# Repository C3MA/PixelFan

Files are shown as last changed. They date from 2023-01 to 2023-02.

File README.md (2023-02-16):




# Projektbeschreibung
In diesem Projekt wurde ein Handelsüblicher Standventilator zum Rotationsdisplay umfunktioniert.

Details und eine Präsentation dazu gibt es hier:

[C3MA Vortrag](https://www.ccc-mannheim.de/wiki/Seminar_17._M%C3%A4rz_2023)

## Aufbau
Es gibt insgesamt 3 identische LED Leisten (PCB/LED_Leiste) mit jeweils 26 HD107S LEDs.

Die LED Leisten werden dann auf der Hauptplatine (PCB/PixelFan) bestückt.

Die Hauptplatine besteht aus 2 Controllern: 

* ein STM32G071KBTX (Software unter STM_PixelFan) für die schnelle zeitkritische Ansteuerung der LEDs und der Synchronisation zur Drehung
* ein ESP32 (Software unter ESP_PixelFan) um per W-LAN eine Verbindung zur Außenwelt herzustellen

Der Ventilator öffnet ein W-LAN (SSID: PixelFan) auf dem er eine Website (unter 192.168.4.1) anzeigt. Auf der Seite können Bilder, Smileys und Text auf den Ventilator gesendet werden.

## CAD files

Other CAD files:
PCB/LED_Leiste_Outline.FCStd
PCB/PCB_Outline.FCStd
PCB/LED_Leiste_Outline.dxf
PCB/PCB_Outline.dxf

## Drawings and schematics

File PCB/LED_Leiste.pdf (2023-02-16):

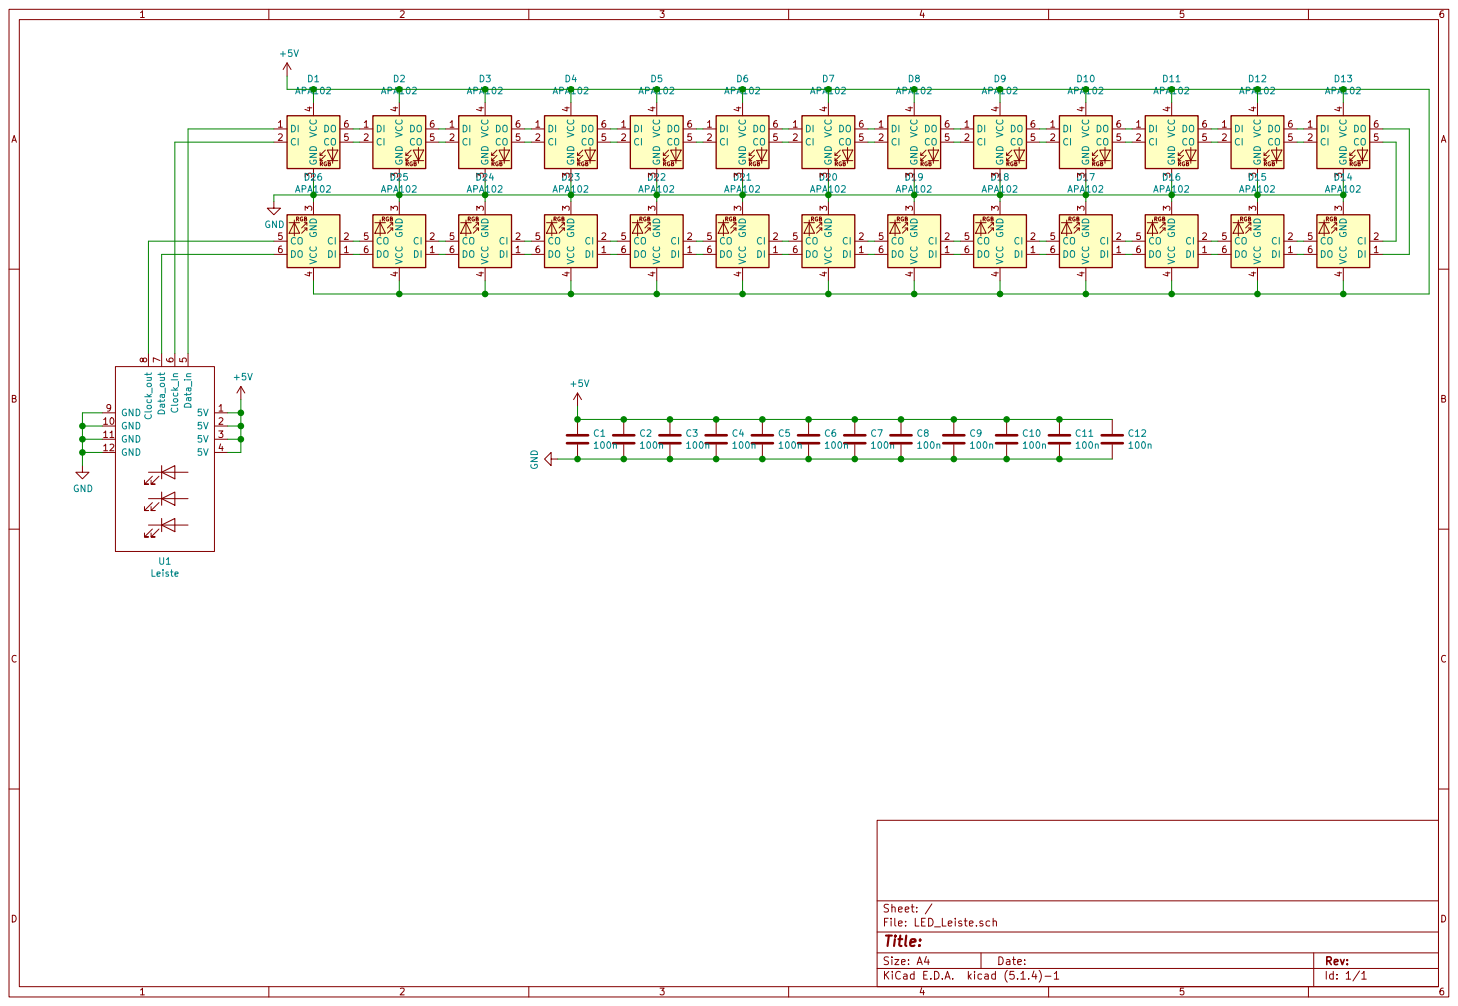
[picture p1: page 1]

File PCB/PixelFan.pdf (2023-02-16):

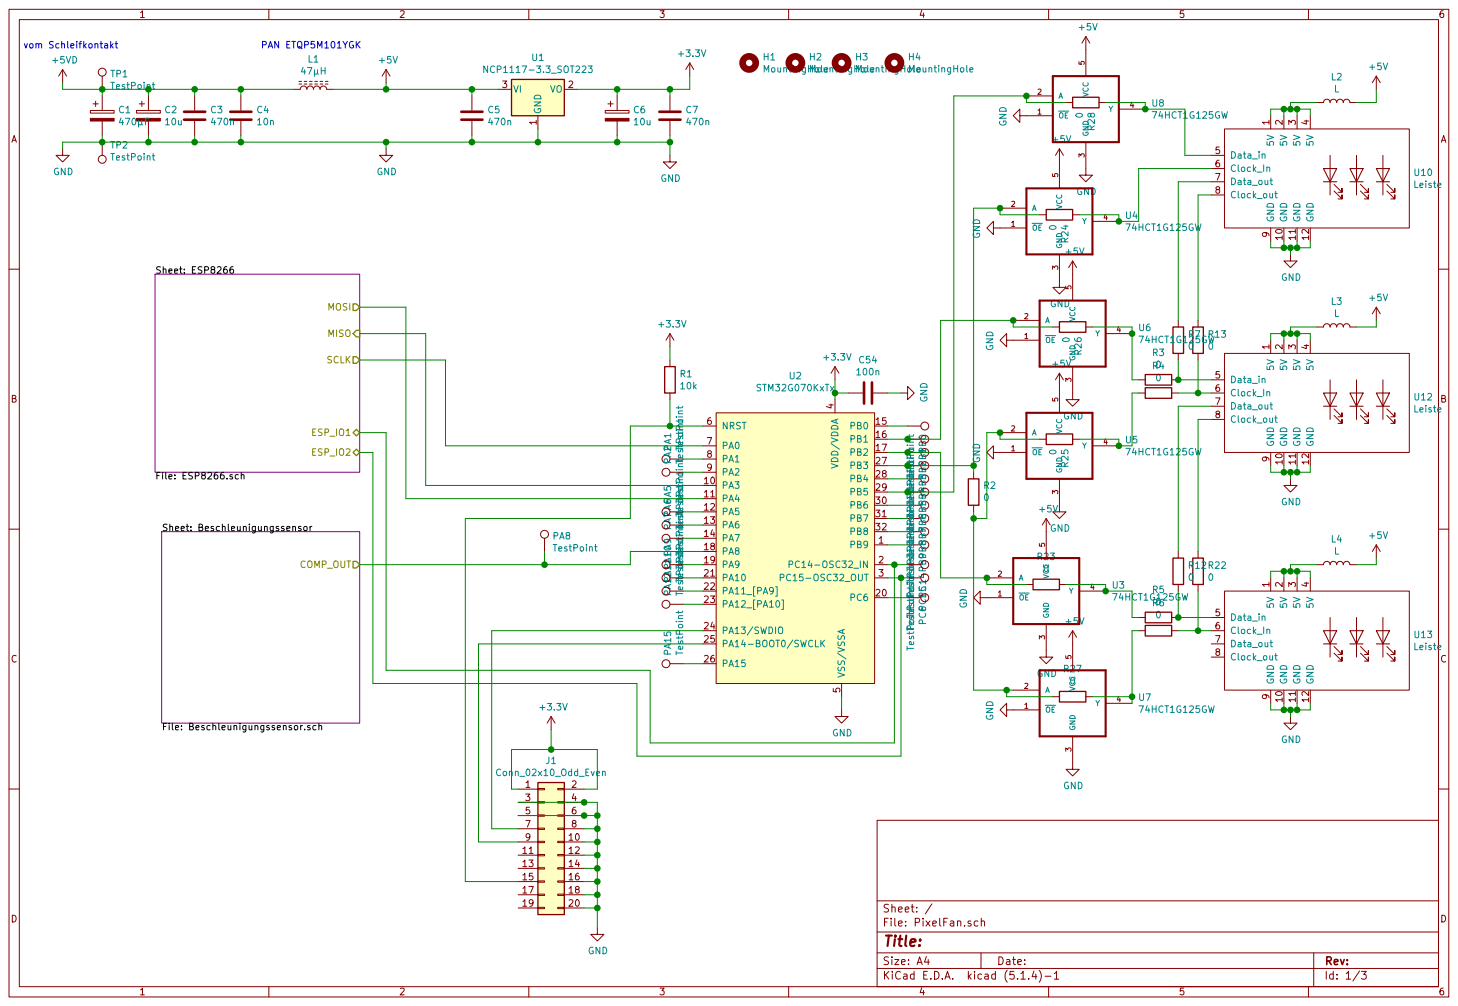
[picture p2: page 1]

Id: 1/3 Title: File: PixelFan.sch Sheet: / Sheet: Beschleunigungssensor

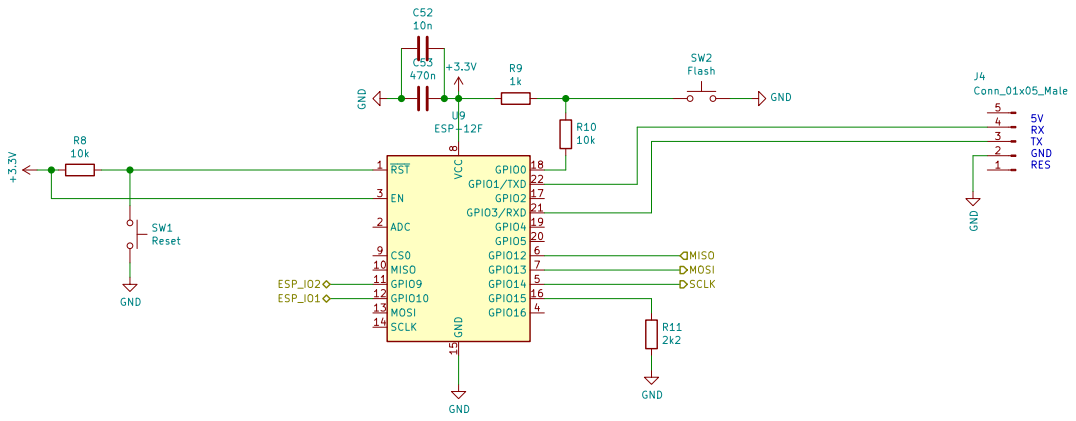
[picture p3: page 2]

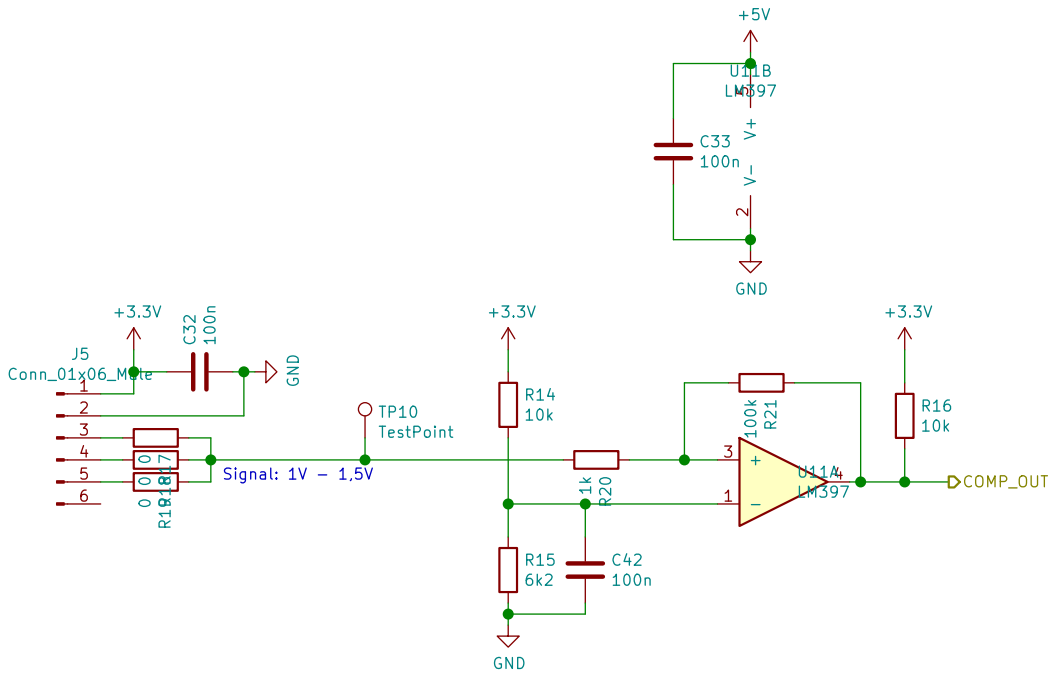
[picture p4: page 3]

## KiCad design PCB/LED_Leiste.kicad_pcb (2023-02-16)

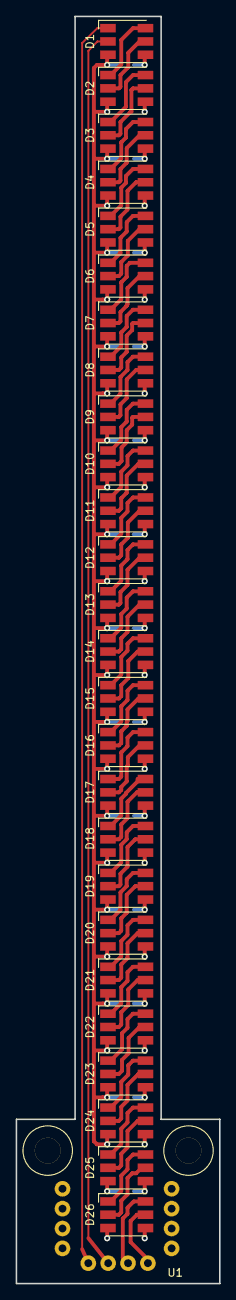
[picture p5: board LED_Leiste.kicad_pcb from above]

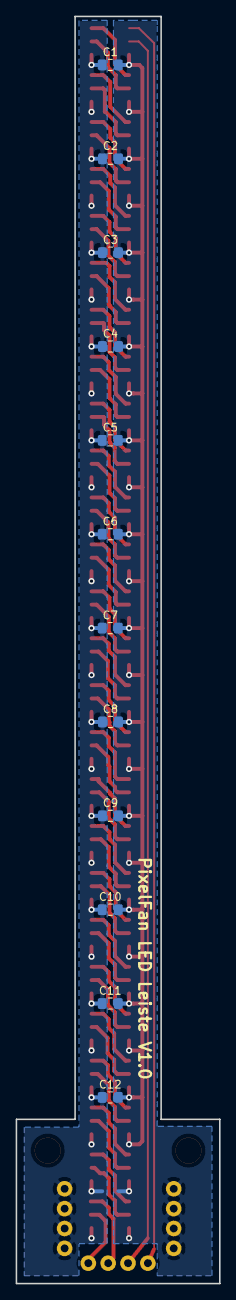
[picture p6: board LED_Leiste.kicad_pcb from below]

Board: 2 copper layers, 26.0 x 162.0 mm, 39 parts (12 on the bottom side), 56 nets.

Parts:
C1, C2, C3, C4, C5, C6, C7, C8, C9, C10, C11, C12: 100n; C_0805_2012Metric_Pad1.15x1.40mm_HandSolder
D1, D2, D3, D4, D5, D6, D7, D8, D9, D10, D11, D12, D13, D14, D15, D16, D17, D18, D19, D20, D21, D22, D23, D24, D25, D26: APA102; LED_RGB_5050-6
U1: Leiste; Leiste_NoOutline

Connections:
+5V: C1.1, C2.1, C3.1, C4.1, C5.1, C6.1, C7.1, C8.1, C9.1, C10.1, C11.1, C12.1, D1.4, D2.4, D3.4, D4.4, D5.4, D6.4, D7.4, D8.4, D9.4, D10.4, D11.4, D12.4, D13.4, D14.4, D15.4, D16.4, D17.4, D18.4, D19.4, D20.4, D21.4, D22.4, D23.4, D24.4, D25.4, D26.4, U1.1, U1.2, U1.3, U1.4
GND: C1.2, C2.2, C3.2, C4.2, C5.2, C6.2, C7.2, C8.2, C9.2, C10.2, C11.2, C12.2, D1.3, D2.3, D3.3, D4.3, D5.3, D6.3, D7.3, D8.3, D9.3, D10.3, D11.3, D12.3, D13.3, D14.3, D15.3, D16.3, D17.3, D18.3, D19.3, D20.3, D21.3, D22.3, D23.3, D24.3, D25.3, D26.3, U1.9, U1.10, U1.11, U1.12
unnamed: D1.1, U1.5
unnamed: D1.2, U1.6
unnamed: D1.5, D2.2
unnamed: D1.6, D2.1
unnamed: D2.5, D3.2
unnamed: D2.6, D3.1
unnamed: D3.5, D4.2
unnamed: D3.6, D4.1
unnamed: D4.5, D5.2
unnamed: D4.6, D5.1
unnamed: D5.5, D6.2
unnamed: D5.6, D6.1
unnamed: D6.5, D7.2
unnamed: D6.6, D7.1
unnamed: D7.5, D8.2
unnamed: D7.6, D8.1
unnamed: D8.5, D9.2
unnamed: D8.6, D9.1
unnamed: D9.6, D10.1
unnamed: D9.5, D10.2
unnamed: D10.5, D11.2
unnamed: D10.6, D11.1
unnamed: D11.5, D12.2
unnamed: D11.6, D12.1
unnamed: D12.5, D13.2
unnamed: D12.6, D13.1
unnamed: D13.5, D14.2
unnamed: D13.6, D14.1
unnamed: D14.5, D15.2
unnamed: D14.6, D15.1
unnamed: D15.5, D16.2
unnamed: D15.6, D16.1
unnamed: D16.5, D17.2
unnamed: D16.6, D17.1
unnamed: D17.5, D18.2
unnamed: D17.6, D18.1
unnamed: D18.5, D19.2
unnamed: D18.6, D19.1
unnamed: D19.5, D20.2
unnamed: D19.6, D20.1
unnamed: D20.5, D21.2
unnamed: D20.6, D21.1
unnamed: D21.5, D22.2
unnamed: D21.6, D22.1
unnamed: D22.5, D23.2
unnamed: D22.6, D23.1
unnamed: D23.5, D24.2
unnamed: D23.6, D24.1
unnamed: D24.5, D25.2
unnamed: D24.6, D25.1
unnamed: D25.5, D26.2
unnamed: D25.6, D26.1
unnamed: D26.5, U1.8
unnamed: D26.6, U1.7

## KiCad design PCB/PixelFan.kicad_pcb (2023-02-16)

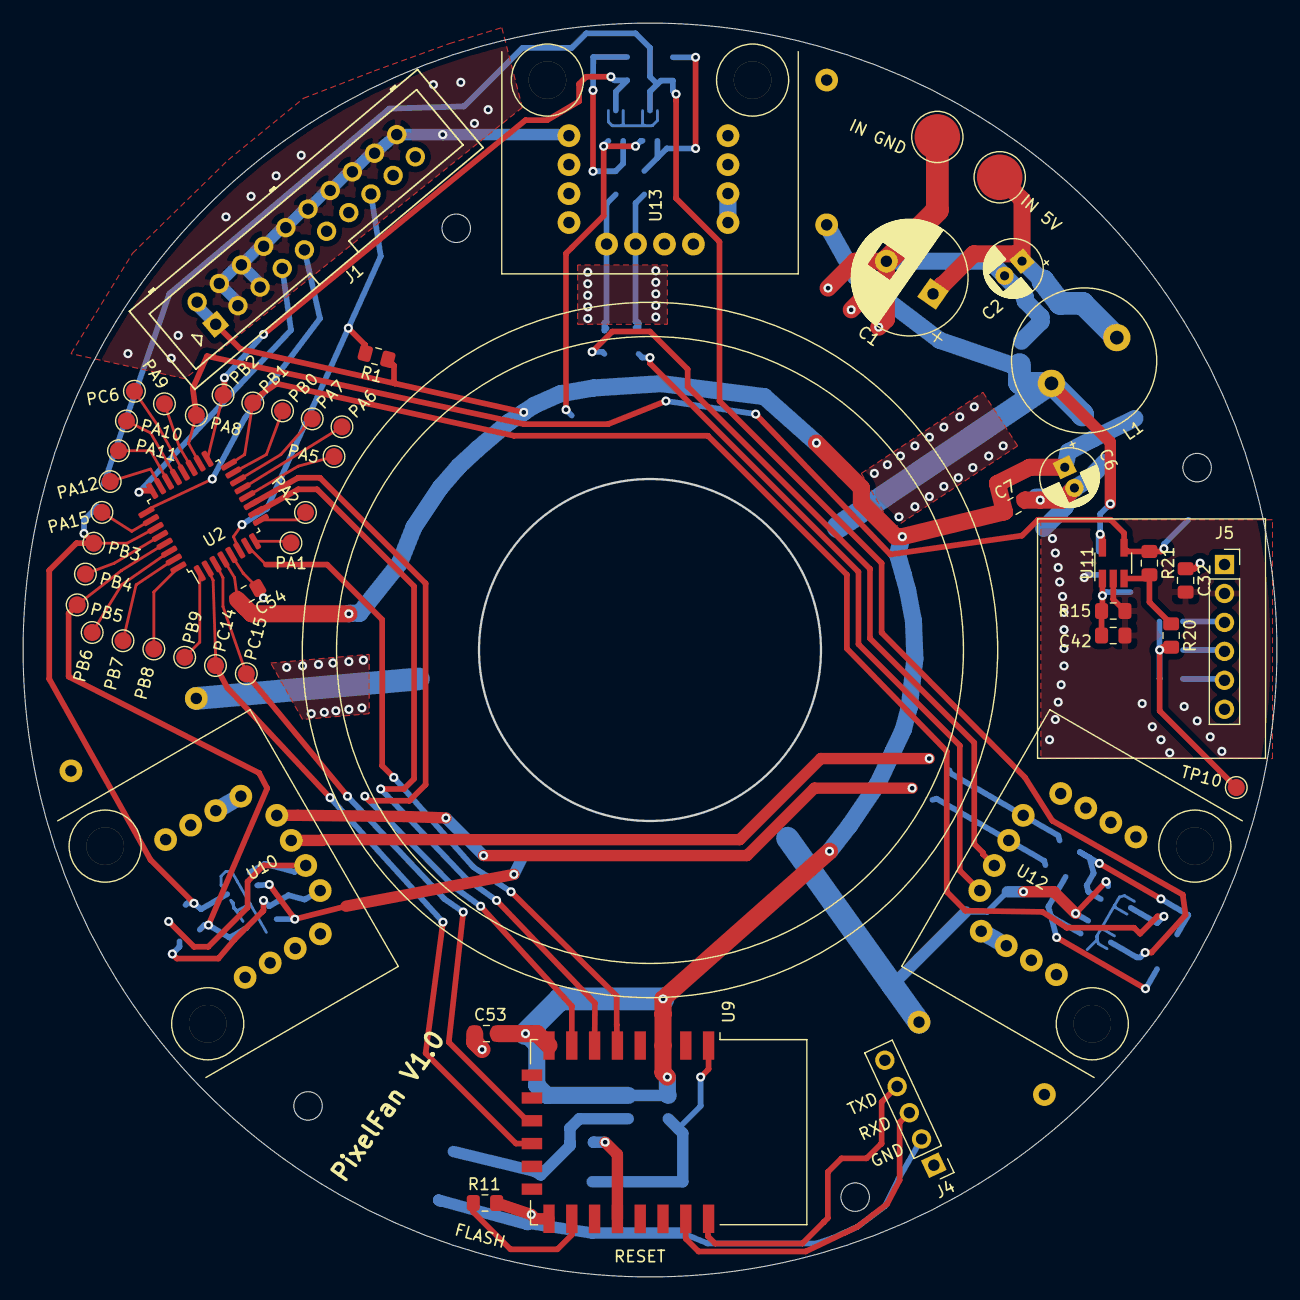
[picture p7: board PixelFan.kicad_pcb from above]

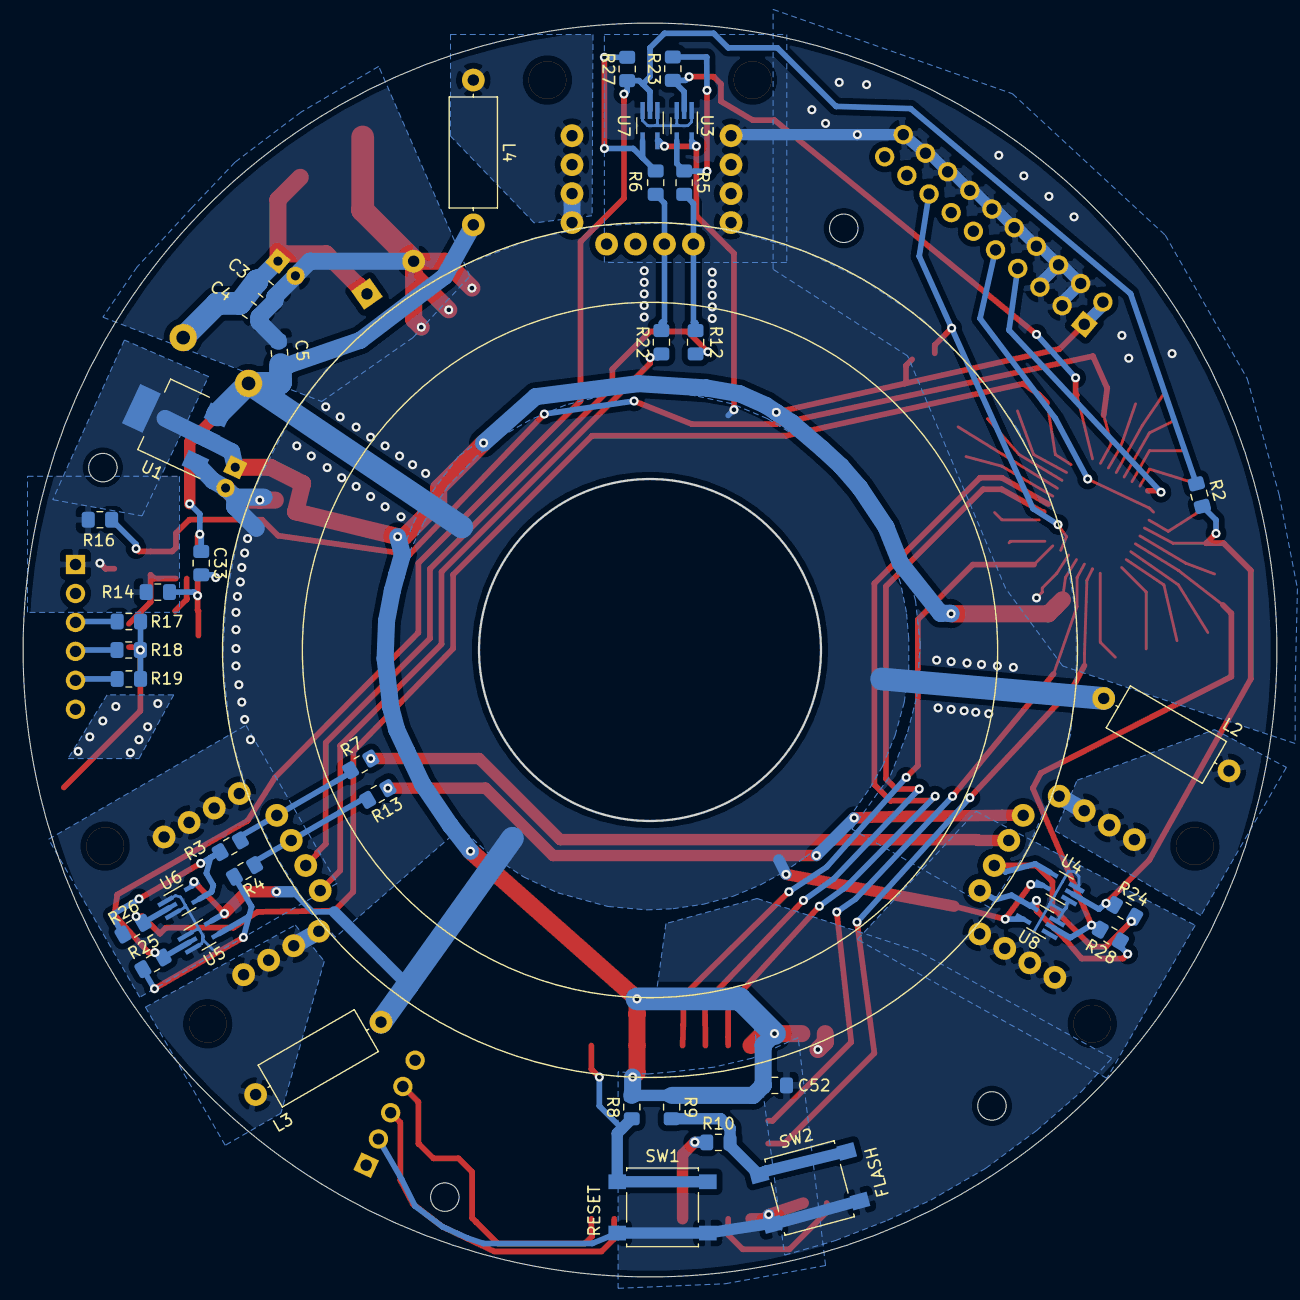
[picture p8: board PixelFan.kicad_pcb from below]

Board: 2 copper layers, 110.0 x 110.0 mm, 94 parts (40 on the bottom side), 64 nets.

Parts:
C1: 470µF; CP_Radial_D10.0mm_P5.00mm
C2, C6: 10u; CP_Radial_D5.0mm_P2.00mm
C3, C5, C7, C53: 470n; C_0805_2012Metric_Pad1.15x1.40mm_HandSolder
C4, C52: 10n; C_0805_2012Metric_Pad1.15x1.40mm_HandSolder
C32, C33, C42, C54: 100n; C_0805_2012Metric_Pad1.15x1.40mm_HandSolder
H1, H2, H3, H4: MountingHole; MountingHole_2.5mm
J1: Conn_02x10_Odd_Even; Multicomp_MC9A12-2034_2x10_P2.54mm_Vertical
J4: Conn_01x05_Male; PinHeader_1x05_P2.54mm_Vertical
J5: Conn_01x06_Male; PinSocket_1x06_P2.54mm_Vertical
L1: 47µH; L_Radial_D12.5mm_P7.00mm_Fastron_09HCP
L2, L3, L4: L; L_Axial_L9.5mm_D4.0mm_P12.70mm_Horizontal_Fastron_SMCC
PA1, PA2, PA5, PA6, PA7, PA8, PA9, PA10, PA11, PA12, PA15: TestPoint; TestPoint_Pad_D1.5mm
PB0, PB1, PB2, PB3, PB4, PB5, PB6, PB7, PB8, PB9: TestPoint; TestPoint_Pad_D1.5mm
PC6, PC14, PC15: TestPoint; TestPoint_Pad_D1.5mm
R1, R8, R10, R14, R16: 10k; R_0805_2012Metric_Pad1.15x1.40mm_HandSolder
R2, R3, R4, R5, R6, R7, R12, R13, R17, R18, R19, R22, R23, R24, R25, R26, R27, R28: 0; R_0805_2012Metric_Pad1.15x1.40mm_HandSolder
R9, R20: 1k; R_0805_2012Metric_Pad1.15x1.40mm_HandSolder
R11: 2k2; R_0805_2012Metric_Pad1.15x1.40mm_HandSolder
R15: 6k2; R_0805_2012Metric_Pad1.15x1.40mm_HandSolder
R21: 100k; R_0805_2012Metric_Pad1.15x1.40mm_HandSolder
SW1: Reset; SW_SPST_B3S-1000
SW2: Flash; SW_SPST_B3S-1000
TP1, TP2: TestPoint; TestPoint_Pad_D4.0mm
TP10: TestPoint; TestPoint_Pad_D1.5mm
U1: NCP1117-3.3_SOT223; SOT-223-3_TabPin2
U2: STM32G070KxTx; LQFP-32_7x7mm_P0.8mm
U3, U4, U5, U6, U7, U8: 74HCT1G125GW; SOT-353_SC-70-5_Handsoldering
U9: ESP-12F; ESP-12E
U10, U12, U13: Leiste; Leiste_WithOutline
U11: LM397; SOT-23-5_HandSoldering

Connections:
+3V3: C6.1, C7.1, C32.1, C52.1, C53.1, C54.2, J1.1, J1.2, J5.1, R1.1, R8.2, R9.1, R14.1, R16.1, U1.2, U2.4, U9.3, U9.8
+5V: C5.1, C33.1, L1.2, L2.2, L3.2, L4.2, U1.3, U3.5, U4.5, U5.5, U6.5, U7.5, U8.5, U11.5
+5VD: C1.1, C2.1, C3.1, C4.1, L1.1, TP1.1
/Beschleunigungssensor/COMP_OUT: PA8.1, R16.2, R21.1, U2.18, U11.4
/ESP8266/ESP_IO1: PC14.1, U2.2, U9.12
/ESP8266/ESP_IO2: PC15.1, U2.3, U9.11
/ESP8266/MISO: U2.10, U9.6
/ESP8266/MOSI: U2.11, U9.7
/ESP8266/SCLK: U2.7, U9.5
GND: C1.2, C2.2, C3.2, C4.2, C5.2, C6.2, C7.2, C32.2, C33.2, C42.2, C52.2, C53.2, C54.1, J1.3, J1.4, J1.5, J1.6, J1.8, J1.10, J1.12, J1.14, J1.16, J1.18, J1.20, J4.2, J5.2, R11.1, R15.2, SW1.2, SW2.2, TP2.1, U1.1, U2.5, U3.1, U3.3, U4.1, U4.3, U5.1, U5.3, U6.1, U6.3, U7.1, U7.3, U8.1, U8.3, U9.15, U10.9, U10.10, U10.11, U10.12, U11.2, U12.9, U12.10, U12.11, U12.12, U13.9, U13.10, U13.11, U13.12
unnamed: C42.1, R14.2, R15.1, U11.1
unnamed: J1.7, U2.24
unnamed: J1.9, U2.25
unnamed: J1.15, R1.2, U2.6
unnamed: J4.3, U9.21
unnamed: J4.4, U9.22
unnamed: J5.3, R17.2
unnamed: J5.4, R18.2
unnamed: J5.5, R19.2
unnamed: L2.1, U10.1, U10.2, U10.3, U10.4
unnamed: L3.1, U12.1, U12.2, U12.3, U12.4
unnamed: L4.1, U13.1, U13.2, U13.3, U13.4
unnamed: PA1.1, U2.8
unnamed: PA2.1, U2.9
unnamed: PA5.1, U2.12
unnamed: PA6.1, U2.13
unnamed: PA7.1, U2.14
unnamed: PA9.1, U2.19
unnamed: PA10.1, U2.21
unnamed: PA11.1, U2.22
unnamed: PA12.1, U2.23
unnamed: PA15.1, U2.26
unnamed: PB0.1, U2.15
unnamed: PB1.1, R26.2, U2.16, U6.2
unnamed: PB2.1, R23.1, U2.17, U3.2
unnamed: PB3.1, R2.2, R24.2, U2.27, U4.2
unnamed: PB4.1, U2.28
unnamed: PB5.1, R28.2, U2.29, U8.2
unnamed: PB6.1, U2.30
unnamed: PB7.1, U2.31
unnamed: PB8.1, U2.32
unnamed: PB9.1, U2.1
unnamed: PC6.1, U2.20
unnamed: R2.1, R25.2, R27.1, U5.2, U7.2
unnamed: R3.1, R7.2, U12.5
unnamed: R7.1, U10.7
unnamed: R8.1, SW1.1, U9.1
unnamed: R10.1, U9.18
unnamed: R9.2, R10.2, SW2.1
unnamed: R11.2, U9.16
unnamed: R12.1, U12.7
unnamed: R5.2, R12.2, U13.5
unnamed: R13.1, U10.8
unnamed: R4.1, R13.2, U12.6
unnamed: R17.1, R18.1, R19.1, R20.2, TP10.1
unnamed: R20.1, R21.2, U11.3
unnamed: R22.1, U12.8
unnamed: R6.2, R22.2, U13.6
unnamed: R5.1, R23.2, U3.4
unnamed: R24.1, U4.4, U10.6
unnamed: R4.2, R25.1, U5.4
unnamed: R3.2, R26.1, U6.4
unnamed: R6.1, R27.2, U7.4
unnamed: R28.1, U8.4, U10.5

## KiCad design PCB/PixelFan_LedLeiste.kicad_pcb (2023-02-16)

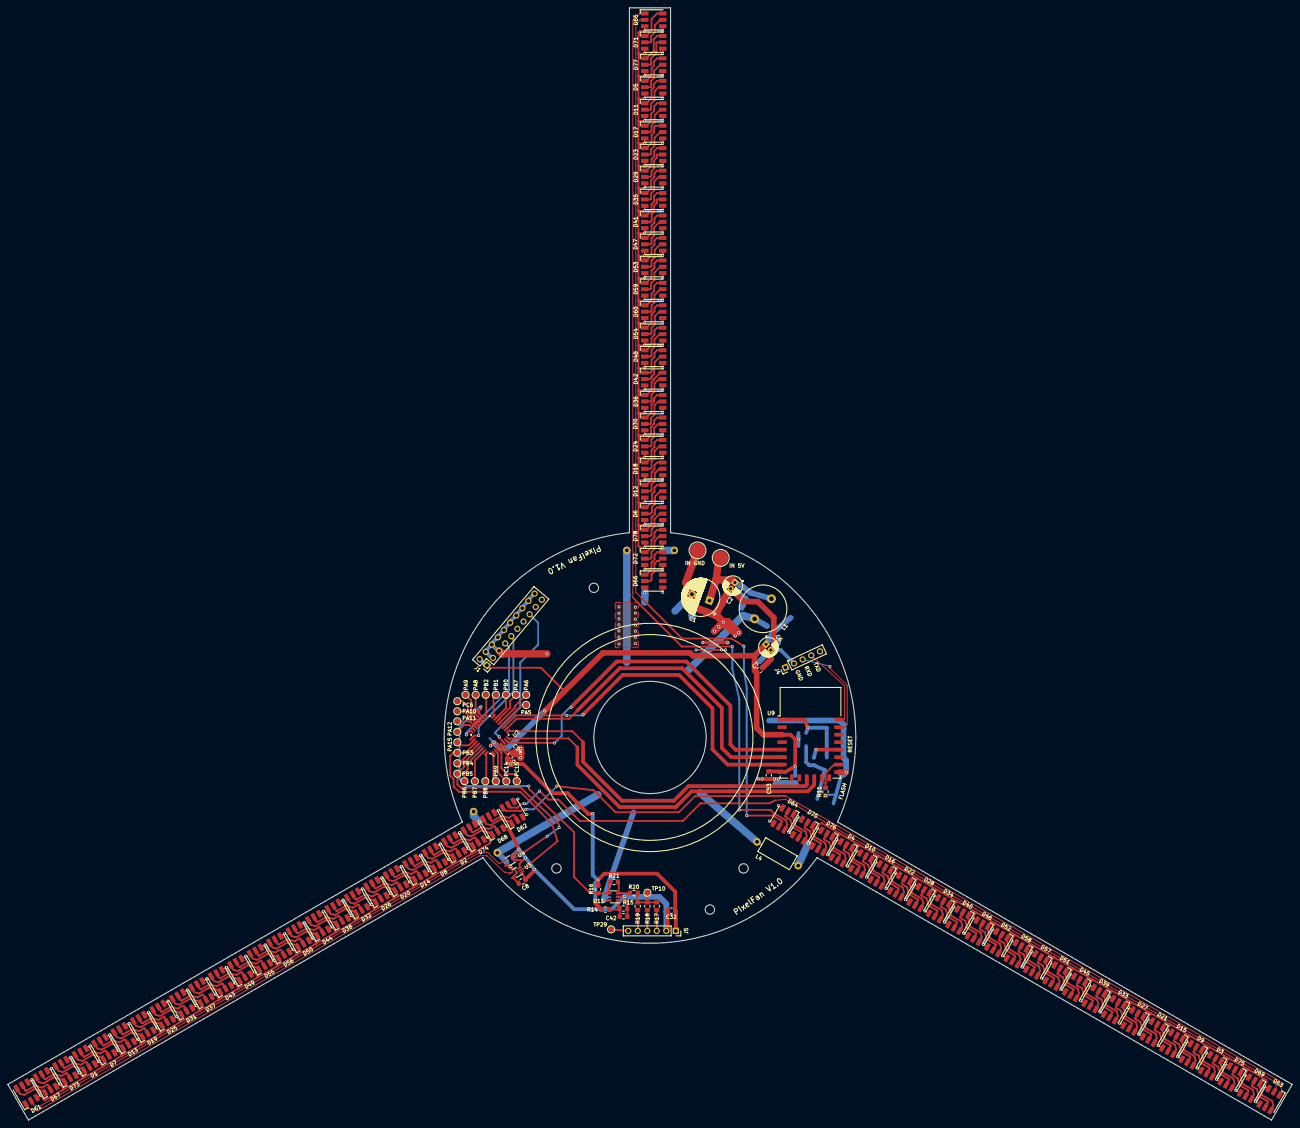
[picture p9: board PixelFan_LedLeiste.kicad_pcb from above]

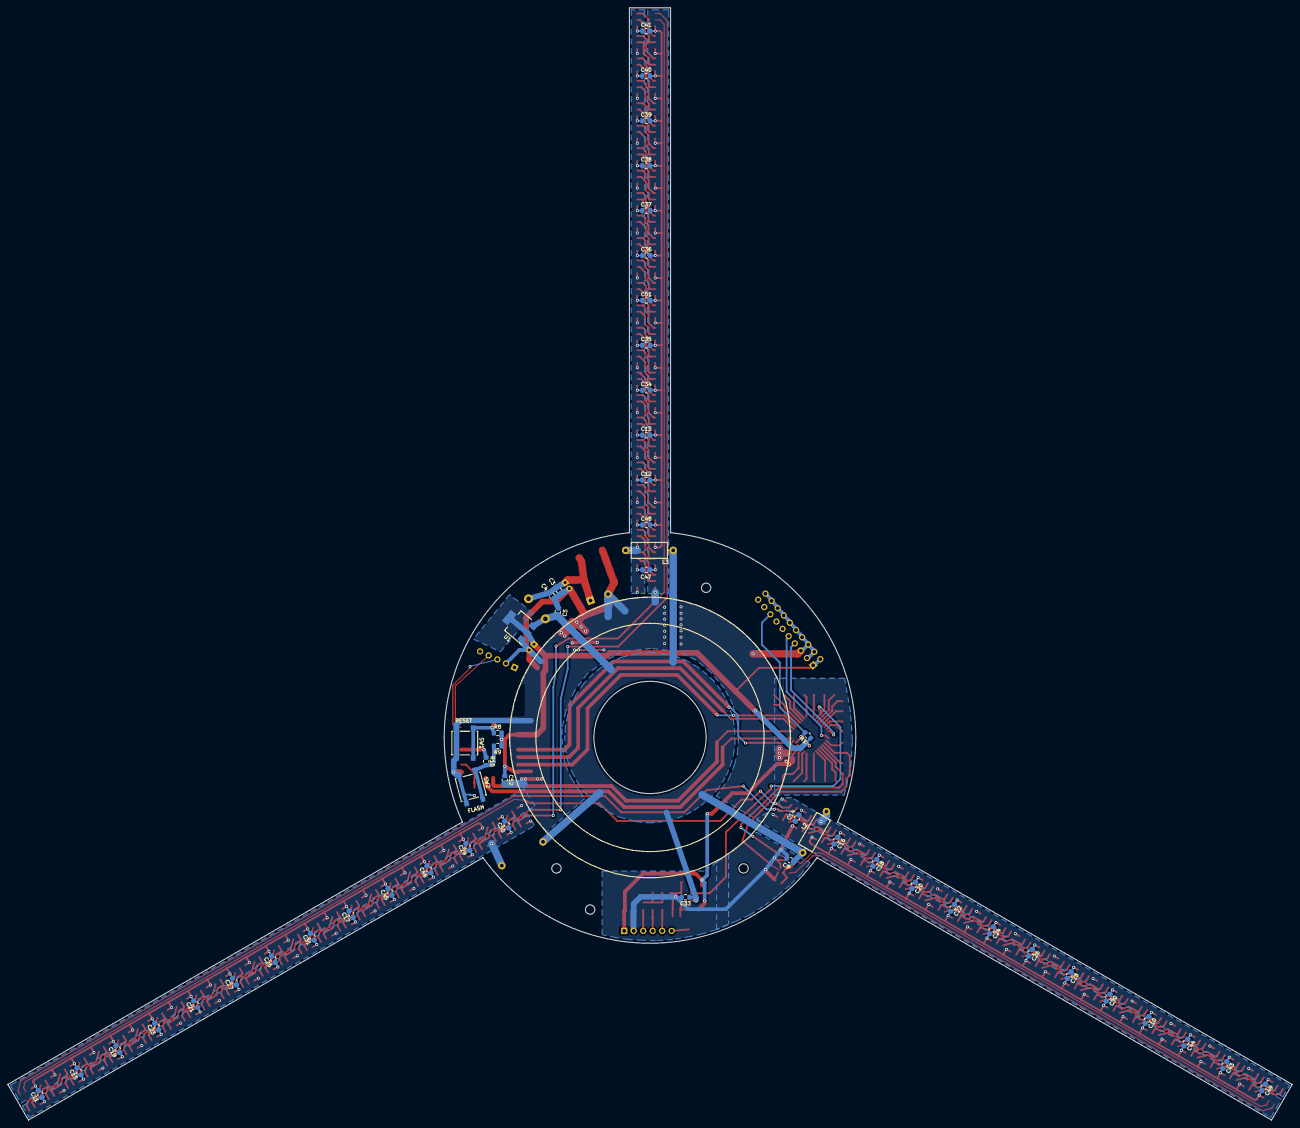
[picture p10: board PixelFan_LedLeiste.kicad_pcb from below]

Board: 2 copper layers, 343.2 x 297.3 mm, 190 parts (54 on the bottom side), 206 nets.

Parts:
C1: 470µF; CP_Radial_D10.0mm_P5.00mm
C2, C6: 10u; CP_Radial_D5.0mm_P2.00mm
C3, C5, C7, C53: 470n; C_0805_2012Metric_Pad1.15x1.40mm_HandSolder
C4, C52: 10n; C_0805_2012Metric_Pad1.15x1.40mm_HandSolder
C8, C9, C10, C11, C12, C13, C14, C15, C16, C17, C18, C19, C20, C21, C22, C23, C24, C25, C26, C27, C28, C29, C30, C31, C32, C33, C34, C35, C36, C37, C38, C39, C40, C41, C42, C43, C44, C45, C46, C47, C48, C49, C50, C51, C54: 100n; C_0805_2012Metric_Pad1.15x1.40mm_HandSolder
D1, D2, D3, D4, D5, D6, D7, D8, D9, D10, D11, D12, D13, D14, D15, D16, D17, D18, D19, D20, D21, D22, D23, D24, D25, D26, D27, D28, D29, D30, D31, D32, D33, D34, D35, D36, D37, D38, D39, D40, D41, D42, D43, D44, D45, D46, D47, D48, D49, D50, D51, D52, D53, D54, D55, D56, D57, D58, D59, D60, D61, D62, D63, D64, D65, D66, D67, D68, D69, D70, D71, D72, D73, D74, D75, D76, D77, D78: APA102; LED_RGB_5050-6
H1, H2, H3, H4: MountingHole; MountingHole_2.5mm
J1: Conn_02x10_Odd_Even; PinHeader_2x10_P2.54mm_Vertical
J4: Conn_01x05_Male; PinHeader_1x05_P2.54mm_Vertical
J5: Conn_01x06_Male; PinSocket_1x06_P2.54mm_Vertical
L1: 47µH; L_Radial_D12.5mm_P7.00mm_Fastron_09HCP
L2, L3, L4: 1u; L_Axial_L9.5mm_D4.0mm_P12.70mm_Horizontal_Fastron_SMCC
PA5, PA6, PA7, PA8, PA9, PA10, PA11, PA12, PA15: TestPoint; TestPoint_Pad_D1.5mm
PB0, PB1, PB2, PB3, PB4, PB5, PB6, PB7, PB8, PB9: TestPoint; TestPoint_Pad_D1.5mm
PC6, PC14, PC15: TestPoint; TestPoint_Pad_D1.5mm
R1, R8, R10, R14, R15, R16: 10k; R_0805_2012Metric_Pad1.15x1.40mm_HandSolder
R9, R20: 1k; R_0805_2012Metric_Pad1.15x1.40mm_HandSolder
R11: 2k2; R_0805_2012Metric_Pad1.15x1.40mm_HandSolder
R17, R18, R19: 0; R_0805_2012Metric_Pad1.15x1.40mm_HandSolder
R21: 100k; R_0805_2012Metric_Pad1.15x1.40mm_HandSolder
SW1: Reset; SW_SPST_B3S-1000
SW2: Flash; SW_SPST_B3S-1000
TP1, TP2: TestPoint; TestPoint_Pad_D4.0mm
TP10, TP29: TestPoint; TestPoint_Pad_D1.5mm
U1: NCP1117-3.3_SOT223; SOT-223-3_TabPin2
U2: STM32G070KxTx; LQFP-32_7x7mm_P0.8mm
U3, U4: 74HCT1G125GW; SOT-353_SC-70-5_Handsoldering
U9: ESP-12F; ESP-12E
U11: LM397; SOT-23-5_HandSoldering

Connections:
+3V3: C6.1, C7.1, C32.1, C52.1, C53.1, C54.2, J1.1, J1.2, J5.1, R1.1, R8.2, R9.1, R14.1, R16.1, U1.2, U2.4, U9.3, U9.8
+5V: C5.1, C8.1, C9.2, C33.1, L1.2, L2.1, L3.1, L4.1, U1.3, U3.5, U4.5, U11.5
+5VD: C1.1, C2.1, C3.1, C4.1, L1.1, TP1.1
/Beschleunigungssensor/COMP_OUT: PA8.1, R16.2, R21.1, U2.18, U11.4
/ESP8266/ESP_IO1: U2.8, U9.12
/ESP8266/ESP_IO2: U2.9, U9.11
/ESP8266/MISO: U2.10, U9.6
/ESP8266/MOSI: U2.11, U9.7
/ESP8266/SCLK: U2.7, U9.5
/LEDs/CLK: PB3.1, U2.27, U3.2
/LEDs/DATA: PB5.1, U2.29, U4.2
/LEDs/VCC_LINE1: C10.1, C14.1, C16.1, C18.1, C20.1, C22.1, C24.1, C26.1, C28.1, C30.1, C43.1, C44.1, C49.1, D1.4, D2.4, D7.4, D8.4, D13.4, D14.4, D19.4, D20.4, D25.4, D26.4, D31.4, D32.4, D37.4, D38.4, D43.4, D44.4, D49.4, D50.4, D55.4, D56.4, D61.4, D62.4, D67.4, D68.4, D73.4, D74.4, L2.2
/LEDs/VCC_LINE2: C11.1, C15.1, C17.1, C19.1, C21.1, C23.1, C25.1, C27.1, C29.1, C31.1, C45.1, C46.1, C50.1, D3.4, D4.4, D9.4, D10.4, D15.4, D16.4, D21.4, D22.4, D27.4, D28.4, D33.4, D34.4, D39.4, D40.4, D45.4, D46.4, D51.4, D52.4, D57.4, D58.4, D63.4, D64.4, D69.4, D70.4, D75.4, D76.4, L4.2
/LEDs/VCC_LINE3: C12.1, C13.1, C34.1, C35.1, C36.1, C37.1, C38.1, C39.1, C40.1, C41.1, C47.1, C48.1, C51.1, D5.4, D6.4, D11.4, D12.4, D17.4, D18.4, D23.4, D24.4, D29.4, D30.4, D35.4, D36.4, D41.4, D42.4, D47.4, D48.4, D53.4, D54.4, D59.4, D60.4, D65.4, D66.4, D71.4, D72.4, D77.4, D78.4, L3.2
GND: C1.2, C2.2, C3.2, C4.2, C5.2, C6.2, C7.2, C8.2, C9.1, C10.2, C11.2, C12.2, C13.2, C14.2, C15.2, C16.2, C17.2, C18.2, C19.2, C20.2, C21.2, C22.2, C23.2, C24.2, C25.2, C26.2, C27.2, C28.2, C29.2, C30.2, C31.2, C32.2, C33.2, C34.2, C35.2, C36.2, C37.2, C38.2, C39.2, C40.2, C41.2, C42.2, C43.2, C44.2, C45.2, C46.2, C47.2, C48.2, C49.2, C50.2, C51.2, C52.2, C53.2, C54.1, D1.3, D2.3, D3.3, D4.3, D5.3, D6.3, D7.3, D8.3, D9.3, D10.3, D11.3, D12.3, D13.3, D14.3, D15.3, D16.3, D17.3, D18.3, D19.3, D20.3, D21.3, D22.3, D23.3, D24.3, D25.3, D26.3, D27.3, D28.3, D29.3, D30.3, D31.3, D32.3, D33.3, D34.3, D35.3, D36.3, D37.3, D38.3, D39.3, D40.3, D41.3, D42.3, D43.3, D44.3, D45.3, D46.3, D47.3, D48.3, D49.3, D50.3, D51.3, D52.3, D53.3, D54.3, D55.3, D56.3, D57.3, D58.3, D59.3, D60.3, D61.3, D62.3, D63.3, D64.3, D65.3, D66.3, D67.3, D68.3, D69.3, D70.3, D71.3, D72.3, D73.3, D74.3, D75.3, D76.3, D77.3, D78.3, J1.3, J1.4, J1.5, J1.6, J1.8, J1.10, J1.12, J1.14, J1.16, J1.18, J1.20, J4.2, J5.2, R11.1, R15.2, SW1.2, SW2.2, TP2.1, U1.1, U2.5, U3.1, U3.3, U4.1, U4.3, U9.15, U11.2
unnamed: C42.1, R14.2, R15.1, U11.1
unnamed: D1.1, D73.6
unnamed: D1.2, D73.5
unnamed: D1.5, D7.2
unnamed: D1.6, D7.1
unnamed: D2.1, D8.6
unnamed: D2.2, D8.5
unnamed: D2.5, D74.2
unnamed: D2.6, D74.1
unnamed: D3.1, D75.6
unnamed: D3.2, D75.5
unnamed: D3.5, D9.2
unnamed: D3.6, D9.1
unnamed: D4.5, D76.2
unnamed: D4.6, D76.1
unnamed: D5.1, D77.6
unnamed: D5.2, D77.5
unnamed: D6.5, D78.2
unnamed: D6.6, D78.1
unnamed: D10.1, D16.6
unnamed: D10.2, D16.5
unnamed: D4.2, D10.5
unnamed: D4.1, D10.6
unnamed: D5.6, D11.1
unnamed: D5.5, D11.2
unnamed: D11.5, D17.2
unnamed: D11.6, D17.1
unnamed: D12.1, D18.6
unnamed: D12.2, D18.5
unnamed: D6.2, D12.5
unnamed: D6.1, D12.6
unnamed: D7.6, D13.1
unnamed: D7.5, D13.2
unnamed: D13.5, D19.2
unnamed: D13.6, D19.1
unnamed: D14.1, D20.6
unnamed: D14.2, D20.5
unnamed: D8.2, D14.5
unnamed: D8.1, D14.6
unnamed: D9.6, D15.1
unnamed: D9.5, D15.2
unnamed: D15.5, D21.2
unnamed: D15.6, D21.1
unnamed: D16.1, D22.6
unnamed: D16.2, D22.5
unnamed: D17.5, D23.2
unnamed: D17.6, D23.1
unnamed: D18.1, D24.6
unnamed: D18.2, D24.5
unnamed: D19.5, D25.2
unnamed: D19.6, D25.1
unnamed: D20.1, D26.6
unnamed: D20.2, D26.5
unnamed: D21.5, D27.2
unnamed: D21.6, D27.1
unnamed: D22.1, D28.6
unnamed: D22.2, D28.5
unnamed: D23.5, D29.2
unnamed: D23.6, D29.1
unnamed: D24.1, D30.6
unnamed: D24.2, D30.5
unnamed: D25.5, D31.2
unnamed: D25.6, D31.1
unnamed: D26.1, D32.6
unnamed: D26.2, D32.5
unnamed: D27.5, D33.2
unnamed: D27.6, D33.1
unnamed: D28.1, D34.6
unnamed: D28.2, D34.5
unnamed: D29.5, D35.2
unnamed: D29.6, D35.1
unnamed: D30.1, D36.6
unnamed: D30.2, D36.5
unnamed: D31.5, D37.2
unnamed: D31.6, D37.1
unnamed: D32.1, D38.6
unnamed: D32.2, D38.5
unnamed: D33.5, D39.2
unnamed: D33.6, D39.1
unnamed: D34.1, D40.6
unnamed: D34.2, D40.5
unnamed: D35.5, D41.2
unnamed: D35.6, D41.1
unnamed: D36.1, D42.6
unnamed: D36.2, D42.5
unnamed: D37.5, D43.2
unnamed: D37.6, D43.1
unnamed: D38.1, D44.6
unnamed: D38.2, D44.5
unnamed: D39.5, D45.2
unnamed: D39.6, D45.1
unnamed: D40.1, D46.6
unnamed: D40.2, D46.5
unnamed: D41.5, D47.2
unnamed: D41.6, D47.1
unnamed: D42.1, D48.6
unnamed: D42.2, D48.5
unnamed: D43.5, D49.2
unnamed: D43.6, D49.1
unnamed: D44.1, D50.6
unnamed: D44.2, D50.5
unnamed: D45.5, D51.2
unnamed: D45.6, D51.1
unnamed: D46.1, D52.6
unnamed: D46.2, D52.5
unnamed: D47.5, D53.2
unnamed: D47.6, D53.1
unnamed: D48.1, D54.6
unnamed: D48.2, D54.5
unnamed: D49.5, D55.2
unnamed: D49.6, D55.1
unnamed: D50.1, D56.6
unnamed: D50.2, D56.5
unnamed: D51.5, D57.2
unnamed: D51.6, D57.1
unnamed: D52.1, D58.6
unnamed: D52.2, D58.5
unnamed: D53.5, D59.2
unnamed: D53.6, D59.1
unnamed: D54.1, D60.6
unnamed: D54.2, D60.5
unnamed: D55.5, D56.2
unnamed: D55.6, D56.1
unnamed: D57.5, D58.2
unnamed: D57.6, D58.1
unnamed: D59.5, D60.2
unnamed: D59.6, D60.1
unnamed: D61.1, U3.4
unnamed: D61.2, U4.4
unnamed: D61.5, D67.2
unnamed: D61.6, D67.1
unnamed: D62.1, D68.6
unnamed: D62.2, D68.5
unnamed: D62.5, D63.2
unnamed: D62.6, D63.1
unnamed: D63.5, D69.2
unnamed: D63.6, D69.1
unnamed: D64.1, D70.6
unnamed: D64.2, D70.5
unnamed: D64.5, D65.2
unnamed: D64.6, D65.1
unnamed: D65.5, D71.2
unnamed: D65.6, D71.1
unnamed: D66.1, D72.6
unnamed: D66.2, D72.5
unnamed: D67.5, D73.2
unnamed: D67.6, D73.1
unnamed: D68.1, D74.6
unnamed: D68.2, D74.5
unnamed: D69.5, D75.2
unnamed: D69.6, D75.1
unnamed: D70.1, D76.6
unnamed: D70.2, D76.5
unnamed: D71.5, D77.2
unnamed: D71.6, D77.1
unnamed: D72.1, D78.6
unnamed: D72.2, D78.5
unnamed: J1.7, U2.24
unnamed: J1.9, U2.25
unnamed: J1.15, R1.2, U2.6
unnamed: J4.3, U9.21
unnamed: J4.4, U9.22
unnamed: J5.3, R17.2
unnamed: J5.4, R18.2
unnamed: J5.5, R19.2
unnamed: J5.6, TP29.1
unnamed: PA5.1, U2.12
unnamed: PA6.1, U2.13
unnamed: PA7.1, U2.14
unnamed: PA9.1, U2.19
unnamed: PA10.1, U2.21
unnamed: PA11.1, U2.22
unnamed: PA12.1, U2.23
unnamed: PA15.1, U2.26
unnamed: PB0.1, U2.15
unnamed: PB1.1, U2.16
unnamed: PB2.1, U2.17
unnamed: PB4.1, U2.28
unnamed: PB6.1, U2.30
unnamed: PB7.1, U2.31
unnamed: PB8.1, U2.32
unnamed: PB9.1, U2.1
unnamed: PC6.1, U2.20
unnamed: PC14.1, U2.2
unnamed: PC15.1, U2.3
unnamed: R8.1, SW1.1, U9.1
unnamed: R10.1, U9.18
unnamed: R9.2, R10.2, SW2.1
unnamed: R11.2, U9.16
unnamed: R17.1, R18.1, R19.1, R20.2, TP10.1
unnamed: R20.1, R21.2, U11.3

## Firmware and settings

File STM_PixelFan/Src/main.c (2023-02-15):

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

/* Includes ------------------------------------------------------------------*/
#include "main.h"

/* USER CODE BEGIN Includes */
#include "SPI_DMA.h"
/* USER CODE END Includes */

SPI_HandleTypeDef hspi1;
SPI_HandleTypeDef hspi2;
DMA_HandleTypeDef hdma_spi1_tx;
DMA_HandleTypeDef hdma_spi2_rx;

TIM_HandleTypeDef htim1;
TIM_HandleTypeDef htim15;

/* USER CODE BEGIN PV */

#define LINES_PER_ROUND 180		//255
#define LINES_DIFF ((LINES_PER_ROUND / 3) * 26)
#define LEDS_PER_LINE 26
#define LINE_ZERO_OFFSET 95	     //lower values = rotate clockwise, bigger value = rotate counter clockwise
#define IMAGE_BUFF_SIZE LINES_PER_ROUND*LEDS_PER_LINE

uint8_t frameStart[4] = {0,0,0,0};
uint8_t frameEnd[8] = {0xFF,0xFF,0xFF,0xFF,0xFF,0xFF,0xFF,0xFF};
uint8_t ledBuff[IMAGE_BUFF_SIZE][4];
uint32_t line_index[3];

uint8_t state = 0;
uint8_t linePos = 0;
uint8_t dmaRunning = 0;
uint32_t globCnt = 0;
uint32_t regCnt = 0;
uint32_t periodAvg = 0;
volatile uint32_t roundComplete = 0;
volatile uint32_t roundSetToZero = 0;

/* USER CODE END PV */

void SystemClock_Config(void);
static void MX_GPIO_Init(void);
static void MX_DMA_Init(void);
static void MX_SPI1_Init(void);
static void MX_TIM15_Init(void);
static void MX_SPI2_Init(void);
static void MX_TIM1_Init(void);
/* USER CODE BEGIN PFP */
void HAL_TIM_PeriodElapsedCallback(TIM_HandleTypeDef *htim);
void HAL_SPI_TxCpltCallback(SPI_HandleTypeDef *hspi);
void clearAllLEDs();
/* USER CODE END PFP */

/**
  * @brief  The application entry point.
  * @retval int
  */
int main(void)
{
  /* USER CODE BEGIN 1 */

	//fill buffer:
	for(uint32_t i = 0; i < IMAGE_BUFF_SIZE; i++)
	{
		ledBuff[i][0] = 0xFF;
		if(i < (IMAGE_BUFF_SIZE/2) + 13)
		{
			ledBuff[i][1] = 6;
			ledBuff[i][2] = 0;
			ledBuff[i][3] = 0;
		}
		else
		{
			ledBuff[i][1] = 0;
			ledBuff[i][2] = 6;
			ledBuff[i][3] = 0;
		}
	}

	line_index[0] = 2*LINES_DIFF;
	line_index[1] = LINES_DIFF;
	line_index[2] = 0;



  /* USER CODE END 1 */
  

  /* MCU Configuration--------------------------------------------------------*/

  /* Reset of all peripherals, Initializes the Flash interface and the Systick. */
  HAL_Init();

  /* Configure the system clock */
  SystemClock_Config();

  /* Initialize all configured peripherals */
  MX_GPIO_Init();
  MX_DMA_Init();
  MX_SPI1_Init();
  MX_TIM15_Init();
  MX_SPI2_Init();
  MX_TIM1_Init();
  /* Infinite loop */
  /* USER CODE BEGIN WHILE */

  clearAllLEDs();

  HAL_Delay(100);

  spi2DmaStart((uint8_t*)ledBuff, IMAGE_BUFF_SIZE*4);	//Start DMA for receiving ESP Data

  HAL_TIM_Base_Start_IT(&htim15);

  HAL_TIM_Base_Start(&htim1);
  TIM1->DIER |= TIM_DIER_CC1IE;
  TIM1->CCER |= TIM_CCER_CC1E;
  TIM1->SMCR |= (0b101 << 4);	//TI1FP1 selected as trigger
  TIM1->SMCR |= 0b100;			//rising edge resets counter
  TIM1->CCMR1 |= (0b1111 << 4);//IC1F Filter
  TIM1->SR = 0;	//Clear all Interrupts

  //uint32_t oldGPIOA = 0;

  while (1)
  {
	  /*if((GPIOA->IDR & (1 << 8)))
	  {
		ledBuff[2][1] = 0;
		ledBuff[2][2] = 0;
		ledBuff[2][3] = 60;
	  }
	  else
	  {
		ledBuff[2][1] = 0;
		ledBuff[2][2] = 0;
		ledBuff[2][3] = 0;
	  }*/
/*
	  if((GPIOA->IDR & (1 << 8)) != oldGPIOA)
	  {
		  if(oldGPIOA != 0)
		  {

				//line_index[0] = 2*LINES_DIFF;
				//line_index[1] = LINES_DIFF;
				//line_index[2] = 0;
			  if(line_index[0] > IMAGE_BUFF_SIZE / 2)
			  {
				  if(TIM15->ARR < 420)
					  TIM15->ARR++;
			  }
			  else
			  {
				  if(TIM15->ARR > 400)
					  TIM15->ARR--;
			  }
		  }

		  oldGPIOA = GPIOA->IDR & (1 << 8);
	  }
*/
    /* USER CODE END WHILE */

    /* USER CODE BEGIN 3 */
  }
  /* USER CODE END 3 */
}

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
/* USER CODE BEGIN 4 */

void TIM15_PeriodElapsedCallback()
{
	HAL_GPIO_TogglePin(GPIOB, GPIO_PIN_6);

	//return;
	if(dmaRunning == 0)// && roundComplete == 0)
	{
		spiDmaStartTransmission(frameStart, 4);
		//HAL_SPI_Transmit_DMA(&hspi1, frameStart, 4);
		dmaRunning = 1;

		if(roundSetToZero == 1)
		{
			//if(line_index[2] - 2 > ((LEDS_PER_LINE*LINE_ZERO_OFFSET)-26) || line_index[2] + 2 < ((LEDS_PER_LINE*LINE_ZERO_OFFSET)-26))
			{
				line_index[2] = (LEDS_PER_LINE*LINE_ZERO_OFFSET)-26;
				line_index[0] = line_index[2] + 2*LINES_DIFF-26;
				line_index[1] = line_index[2] + LINES_DIFF-26;
			}
			roundSetToZero = 0;
		}
	}

}

void SPI_DMA_Irq()
{
	DMA1->IFCR |= DMA_IFCR_CTCIF1;		//clear interrupts
	DMA1->IFCR |= DMA_IFCR_CGIF1;		//clear interrupts
	DMA1->IFCR |= DMA_IFCR_CHTIF1;
	DMA1->IFCR |= DMA_IFCR_CTEIF1;


	if(state == 0)
	{
		spiDmaStartTransmission(&ledBuff[line_index[linePos]][0], (uint16_t)(4*26));

		linePos++;

		if(linePos == 3)
		{
			state = 1;
		}
	}
	else if(state == 1)
	{
		spiDmaStartTransmission(frameEnd, 5);
		state = 2;
	}
	else if(state == 2)
	{
		linePos = 0;
		state = 0;
		dmaRunning = 0;

		line_index[0]+=26;
		line_index[1]+=26;
		line_index[2]+=26;

		if(line_index[0] >= IMAGE_BUFF_SIZE) line_index[0] -= IMAGE_BUFF_SIZE;
		if(line_index[1] >= IMAGE_BUFF_SIZE) line_index[1] -= IMAGE_BUFF_SIZE;
		if(line_index[2] >= IMAGE_BUFF_SIZE) line_index[2] -= IMAGE_BUFF_SIZE;
	}

}

void SPI2_ESP_IRQ()
{
	static uint32_t pnt = 0;
	static uint32_t subPnt = 0;
	SPI2->CR1 |= SPI_CR1_SSI;
	uint8_t data;

	//ledBuff[oldSpiData][2] = 0;

	while(((SPI2->SR & SPI_SR_FRLVL) >> SPI_SR_FRLVL_Pos) > 0)
	{
		//read all Data
		data = SPI2->DR;

		ledBuff[pnt][subPnt] = data;

		subPnt++;

		if(subPnt == 4)
		{
			subPnt = 0;
			pnt++;

			if(pnt == IMAGE_BUFF_SIZE)
			{
				pnt = 0;
			}
		}
	}

	SPI2->CR1 &= ~SPI_CR1_SSI;
}

void TIM1_InputCapture_IRQ()
{
	//One round complete (Input Capture triggered from Hallsensor)

	uint32_t period = TIM1->CCR1;

	roundSetToZero = 1;

	periodAvg += period;

	regCnt++;
	if(regCnt == 32)
	{
		//periodAvg = (periodAvg << 0);	//Durch 32 für Mittelung, Mal 32 für gleiche Zeitbasis => Mal 1

		periodAvg /= LINES_PER_ROUND;

		if(periodAvg > 3500 && periodAvg < 65000)
		{
			TIM15->ARR = periodAvg-2;
			ledBuff[0][3] = 0;
			ledBuff[0][2] = 150;
		}
		else
		{
			ledBuff[0][2] = 0;
			ledBuff[0][3] = 150;
		}

		regCnt = 0;
		periodAvg = 0;
	}


}

void SPI2_DMA_Irq()	//SPI vom ESP
{
	//restart DMA
	spi2DmaStart((uint8_t*)ledBuff, IMAGE_BUFF_SIZE*4);
}

void clearAllLEDs()
{
	uint8_t tmpBuf[4] = {0,0,0,0};
	HAL_SPI_Transmit(&hspi1, tmpBuf, 4, HAL_MAX_DELAY);

	tmpBuf[0] = 0xFF;

	for(int i = 1; i <= 83; i++)
	{
	  HAL_SPI_Transmit(&hspi1, tmpBuf, 4, HAL_MAX_DELAY);
	}

	HAL_Delay(10);
}
/* USER CODE END 4 */
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


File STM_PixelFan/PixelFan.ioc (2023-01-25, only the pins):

Mcu.UserName=STM32G071KBTx
PA0.Signal=SPI2_SCK
PA4.Signal=SPI2_MOSI
PA8.Signal=S_TIM1_CH1
PB3.Signal=SPI1_SCK
PB5.Signal=SPI1_MOSI
PB6.Signal=GPIO_Output

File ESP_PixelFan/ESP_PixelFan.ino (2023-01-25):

#include <ESP8266WiFi.h>
#include <WiFiClient.h>
#include <SPI.h>
#include "src/MyWebserver.hpp"
#include "src/MyWebsocketServer.hpp"

/* Set these to your desired credentials. */
const char *ssid = "PixelFan";
const char *password = "";

#define LINES_PER_ROUND 180
#define LEDS_PER_LINE 26

uint8_t ledBuff[LINES_PER_ROUND*LEDS_PER_LINE][4];

WiFiServer dnsServer(53);
MyWebserver pixelFanWebserver;
MyWebsocketServer websocketServer(81);

/* Just a little test message.  Go to http://192.168.4.1 in a web browser
   connected to this access point to see it.
*/


void setup() {
  SPI.setFrequency(8000000);
  SPI.setBitOrder(MSBFIRST);
  SPI.begin();

  delay(5000);
  Serial.begin(115200);
  Serial.println();
  Serial.print("Configuring access point...");
  /* You can remove the password parameter if you want the AP to be open. */
  WiFi.softAP(ssid, password);

  IPAddress myIP = WiFi.softAPIP();
  Serial.print("AP IP address: ");
  Serial.println(myIP);

  pixelFanWebserver.init();
  
  Serial.println("Web server started");

  dnsServer.begin();
  Serial.println("DNS server started");

  websocketServer.begin();

  //fill buffer:
	for(uint32_t i = 0; i < LINES_PER_ROUND*LEDS_PER_LINE; i++)
	{
    if(i < LINES_PER_ROUND*LEDS_PER_LINE/2)
    {
      ledBuff[i][0] = 0xFF;
      ledBuff[i][1] = 0;
      ledBuff[i][2] = 0;
      ledBuff[i][3] = 6;
    }
    else
    {
      ledBuff[i][0] = 0xFF;
      ledBuff[i][1] = 6;
      ledBuff[i][2] = 0;
      ledBuff[i][3] = 6;
    }
	}

  SPI.setFrequency(8000000);
  SPI.setBitOrder(MSBFIRST);
  SPI.begin();

}

void loop() {
  static uint32_t cnt = 0;

  pixelFanWebserver.loop();
  websocketServer.loop();

  cnt++;

  if(cnt == 800)
  {
    if(websocketServer.newImage())
    {
      for(int i = 0; i < LINES_PER_ROUND*LEDS_PER_LINE; i++)
      {
        SPI.transfer(ledBuff[i][0]);
        SPI.transfer(ledBuff[i][1]);
        SPI.transfer(ledBuff[i][2]);
        SPI.transfer(ledBuff[i][3]);
      }
    }
    cnt = 0;
  }


  /*WiFiClient client = dnsServer.available();
 
  if (client) {
 
    while (client.connected()) {
 
      while (client.available()>0) {
        char c = client.read();
        Serial.write(c);
      }
 
      delay(10);
    }
 
    client.stop();
    Serial.println("Client disconnected");
 
  }*/
}

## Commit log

2023-01-26 arduino install script for action
2023-01-26 Arduino Build with ESP core
2023-02-16 Check In PCB Files
    [Beschleunigungssensor.sch, ESP8266.sch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]

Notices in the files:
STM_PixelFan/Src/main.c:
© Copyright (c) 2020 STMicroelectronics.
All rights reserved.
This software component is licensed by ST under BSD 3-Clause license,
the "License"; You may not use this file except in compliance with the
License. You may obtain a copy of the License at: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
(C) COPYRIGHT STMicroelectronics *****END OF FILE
